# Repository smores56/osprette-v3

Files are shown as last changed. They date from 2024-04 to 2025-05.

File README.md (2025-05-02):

The Osprette V3
=============

The Osprette V3 is the 3rd revision of the [Osprette][osprette]. It's a 34-key unibody that runs on any pro-micro compatible daughterboard. It comes with bluetooth support by way of battery terminals and a power switch. It is direct solder (AKA no hotswap) for maximum stability of the switches.

# Ordering One

To order one of these from JLC, just upload the `osprette_v3.zip` archive to the Order Now page at <https://jlcpcb.com>,
and make sure to set a 1.6mm thickness. Removing the order number is always recommended.

# Pictures

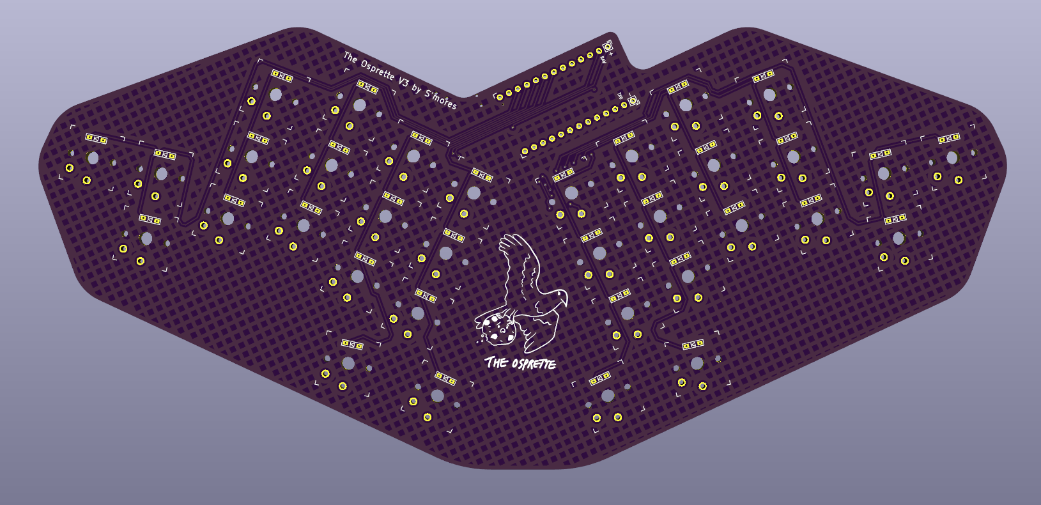
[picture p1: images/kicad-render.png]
KiCad Render


_More to come when PCB's arrive!_

[osprette]: https://github.com/smores56/osprette

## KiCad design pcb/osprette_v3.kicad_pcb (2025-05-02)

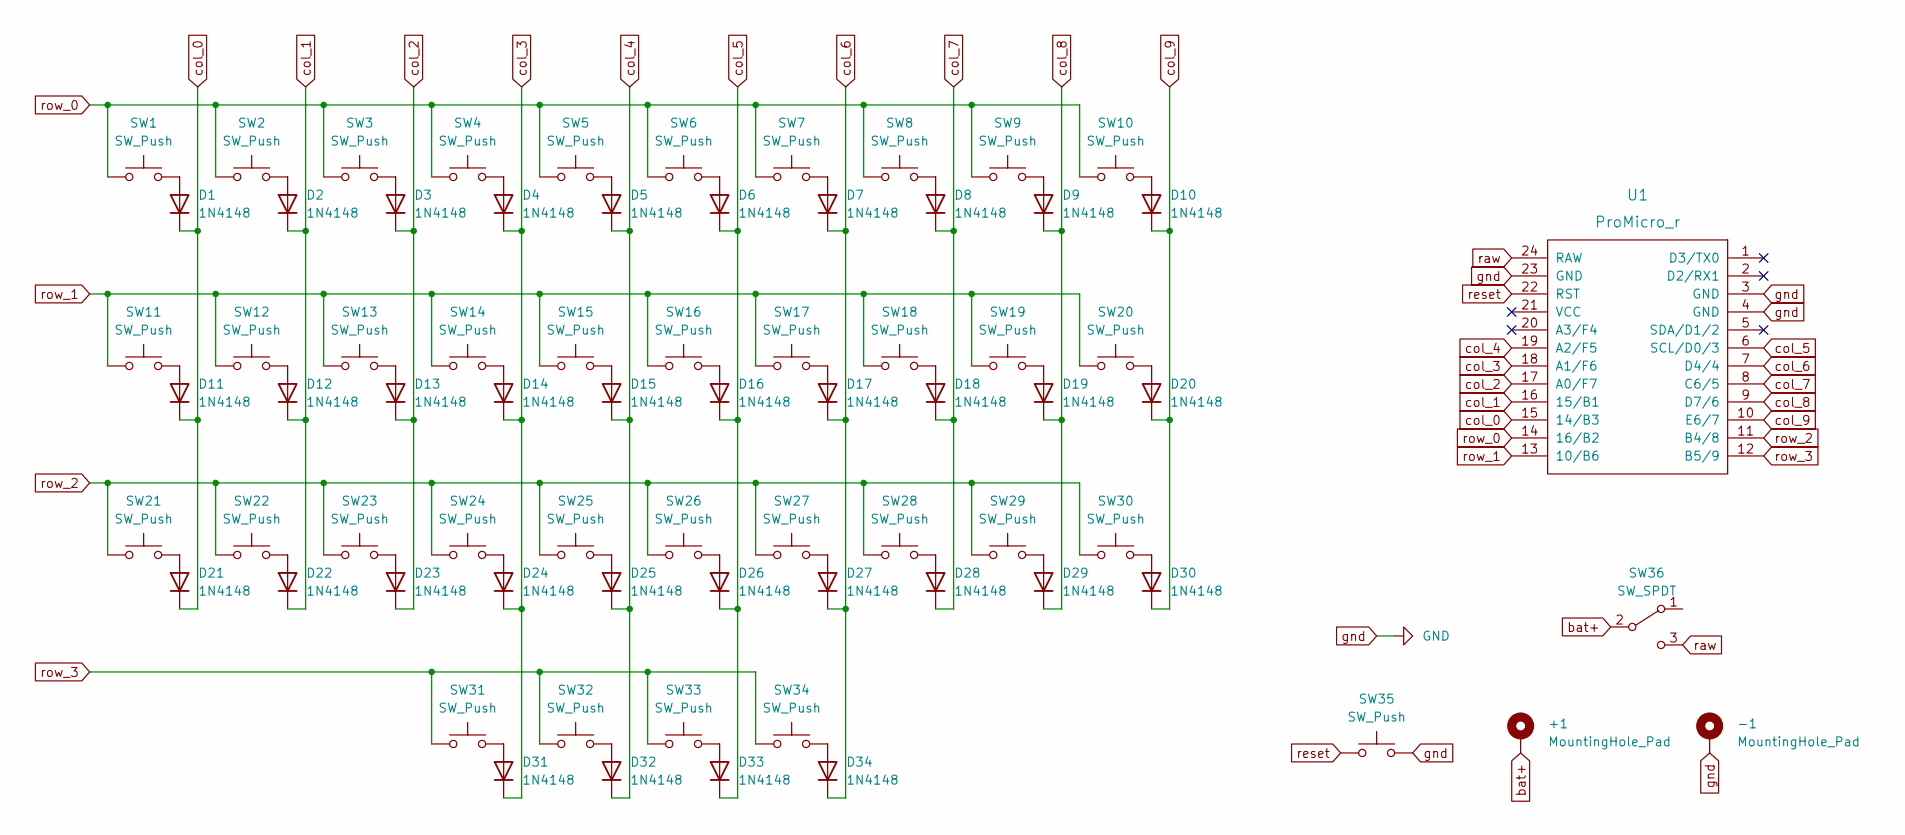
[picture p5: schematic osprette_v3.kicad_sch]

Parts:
+1: MountingHole_Pad; single-pin
-1: MountingHole_Pad; single-pin
D1, D2, D3, D4, D5, D6, D7, D8, D9, D10, D11, D12, D13, D14, D15, D16, D17, D18, D19, D20, D21, D22, D23, D24, D25, D26, D27, D28, D29, D30, D31, D32, D33, D34: 1N4148; smd-diode
SW1, SW2, SW3, SW4, SW5, SW6, SW7, SW8, SW9, SW10, SW11, SW12, SW13, SW14, SW15, SW16, SW17, SW18, SW19, SW20, SW21, SW22, SW23, SW24, SW25, SW26, SW27, SW28, SW29, SW30, SW31, SW32, SW33, SW34: SW_Push; choc-switch-one-sided
SW35: SW_Push; reset-switch-angled-4pin
SW36: SW_SPDT; power-switch
U1: ProMicro_r; pro-micro

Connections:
unnamed: D1.2 (A), SW1.2
unnamed: D2.2 (A), SW2.2
unnamed: D3.2 (A), SW3.2
unnamed: D4.2 (A), SW4.2
unnamed: D5.2 (A), SW5.2
unnamed: D6.2 (A), SW6.2
unnamed: D7.2 (A), SW7.2
unnamed: D8.2 (A), SW8.2
unnamed: D9.2 (A), SW9.2
unnamed: D10.2 (A), SW10.2
unnamed: D11.2 (A), SW11.2
unnamed: D12.2 (A), SW12.2
unnamed: D13.2 (A), SW13.2
unnamed: D14.2 (A), SW14.2
unnamed: D15.2 (A), SW15.2
unnamed: D16.2 (A), SW16.2
unnamed: D17.2 (A), SW17.2
unnamed: D18.2 (A), SW18.2
unnamed: D19.2 (A), SW19.2
unnamed: D20.2 (A), SW20.2
unnamed: D21.2 (A), SW21.2
unnamed: D22.2 (A), SW22.2
unnamed: D23.2 (A), SW23.2
unnamed: D24.2 (A), SW24.2
unnamed: D25.2 (A), SW25.2
unnamed: D26.2 (A), SW26.2
unnamed: D27.2 (A), SW27.2
unnamed: D28.2 (A), SW28.2
unnamed: D29.2 (A), SW29.2
unnamed: D30.2 (A), SW30.2
unnamed: D31.2 (A), SW31.2
unnamed: D32.2 (A), SW32.2
unnamed: D33.2 (A), SW33.2
unnamed: D34.2 (A), SW34.2
bat+: +1.1, SW36.2 (B)
col_0: D1.1 (K), D11.1 (K), D21.1 (K), U1.15 (14/B3)
col_1: D2.1 (K), D12.1 (K), D22.1 (K), U1.16 (15/B1)
col_2: D3.1 (K), D13.1 (K), D23.1 (K), U1.17 (A0/F7)
col_3: D4.1 (K), D14.1 (K), D24.1 (K), D31.1 (K), U1.18 (A1/F6)
col_4: D5.1 (K), D15.1 (K), D25.1 (K), D32.1 (K), U1.19 (A2/F5)
col_5: D6.1 (K), D16.1 (K), D26.1 (K), D33.1 (K), U1.6 (SCL/D0/3)
col_6: D7.1 (K), D17.1 (K), D27.1 (K), D34.1 (K), U1.7 (D4/4)
col_7: D8.1 (K), D18.1 (K), D28.1 (K), U1.8 (C6/5)
col_8: D9.1 (K), D19.1 (K), D29.1 (K), U1.9 (D7/6)
col_9: D10.1 (K), D20.1 (K), D30.1 (K), U1.10 (E6/7)
gnd: -1.1, SW35.2, U1.3 (GND), U1.4 (GND), U1.23 (GND)
raw: SW36.3 (C), U1.24 (RAW)
reset: SW35.1, U1.22 (RST)
row_0: SW1.1, SW2.1, SW3.1, SW4.1, SW5.1, SW6.1, SW7.1, SW8.1, SW9.1, SW10.1, U1.14 (16/B2)
row_1: SW11.1, SW12.1, SW13.1, SW14.1, SW15.1, SW16.1, SW17.1, SW18.1, SW19.1, SW20.1, U1.13 (10/B6)
row_2: SW21.1, SW22.1, SW23.1, SW24.1, SW25.1, SW26.1, SW27.1, SW28.1, SW29.1, SW30.1, U1.11 (B4/8)
row_3: SW31.1, SW32.1, SW33.1, SW34.1, U1.12 (B5/9)

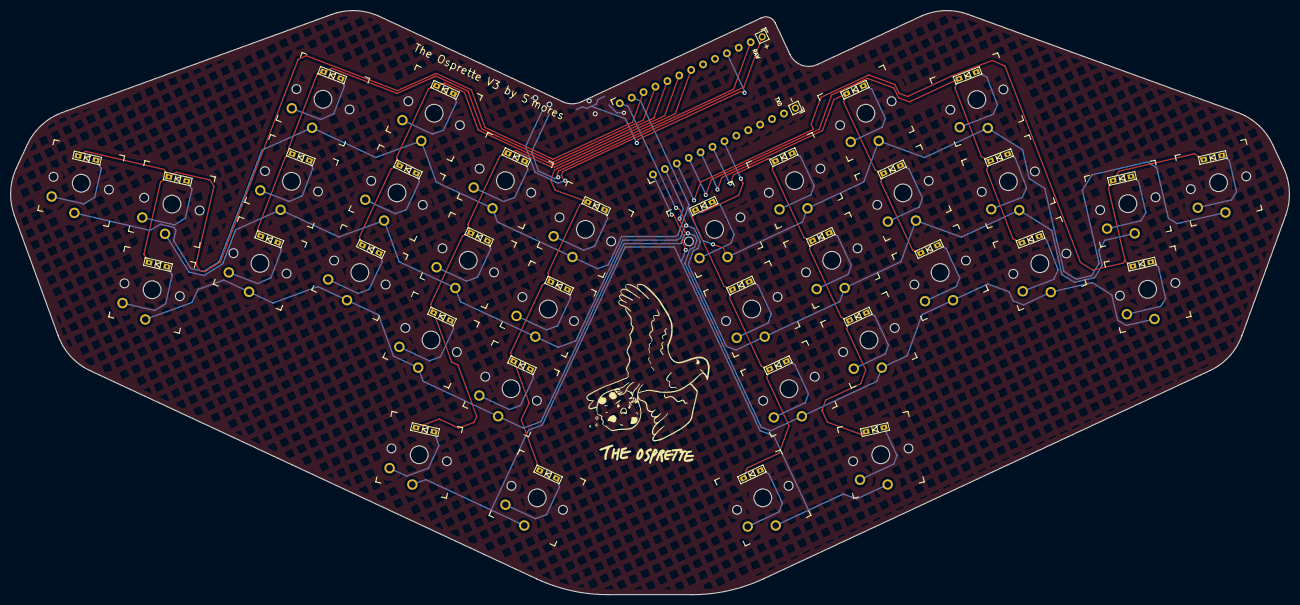
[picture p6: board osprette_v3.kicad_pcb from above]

Board: 2 copper layers, 247.3 x 113.0 mm, 73 parts (1 on the bottom side), 52 nets.
